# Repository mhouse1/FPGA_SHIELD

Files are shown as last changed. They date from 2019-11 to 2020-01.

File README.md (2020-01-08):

# FPGA_SHIELD
An awsome shield that supports multiple tranceivers

* Main schematic view
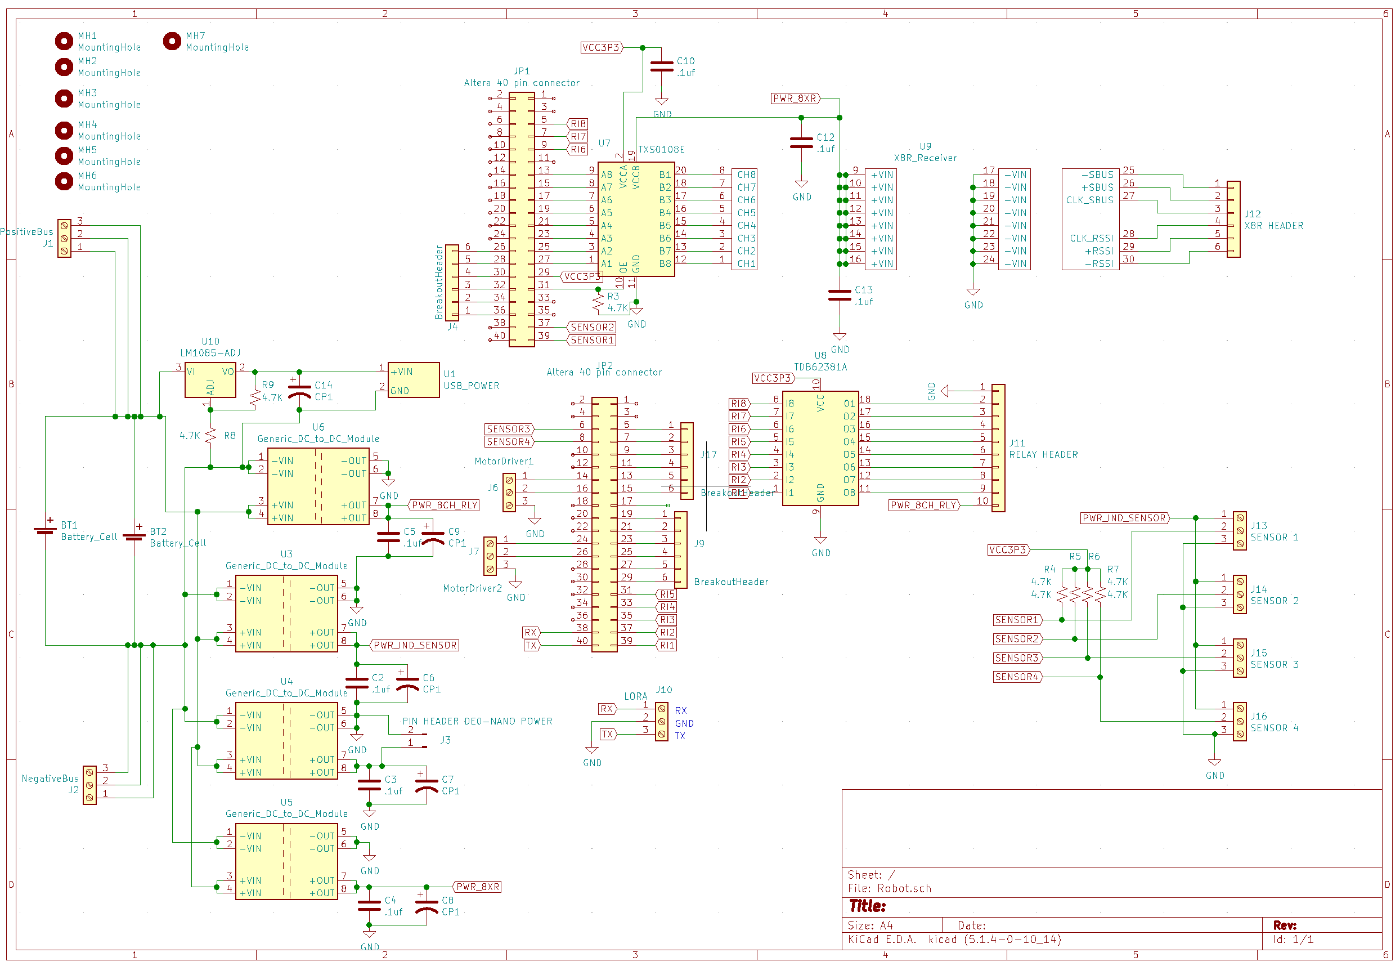
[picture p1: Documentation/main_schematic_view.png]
Main Schematic View


* board layout
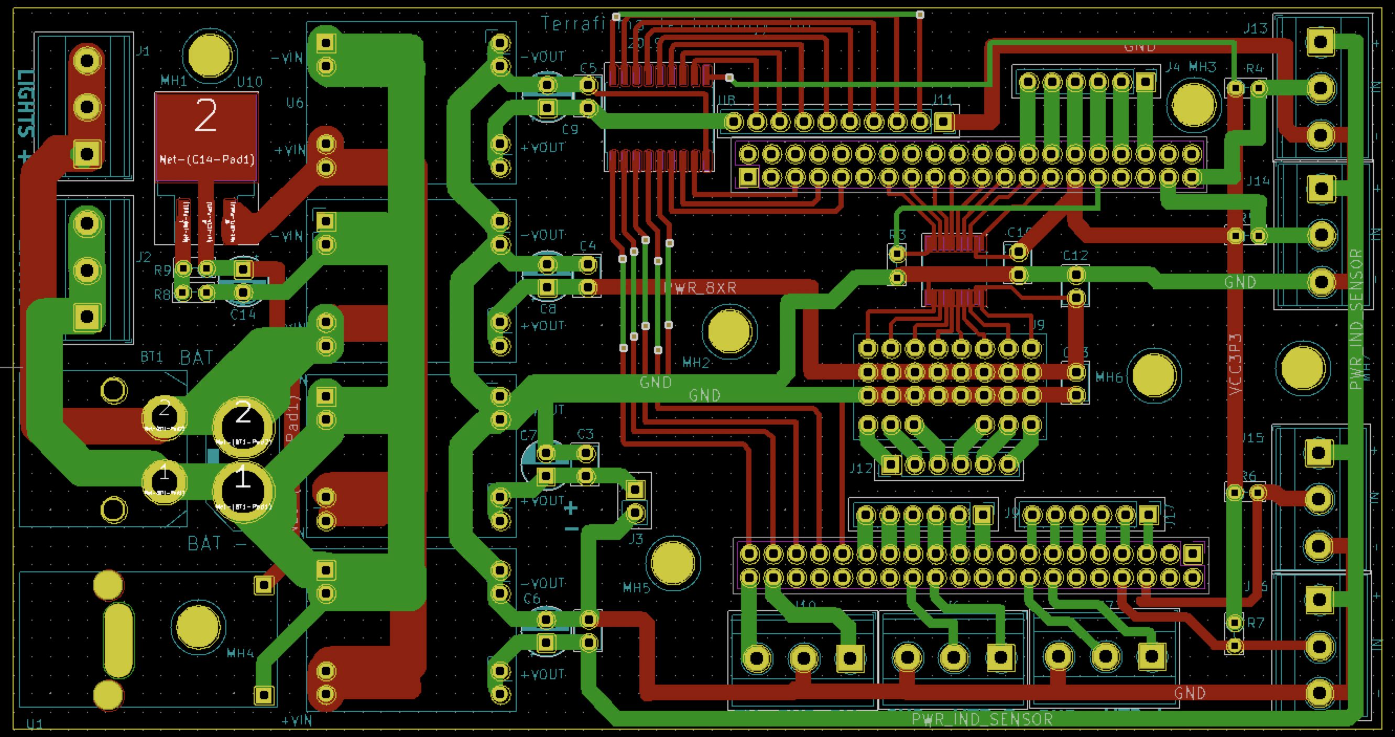
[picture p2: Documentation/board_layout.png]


* board model view 1
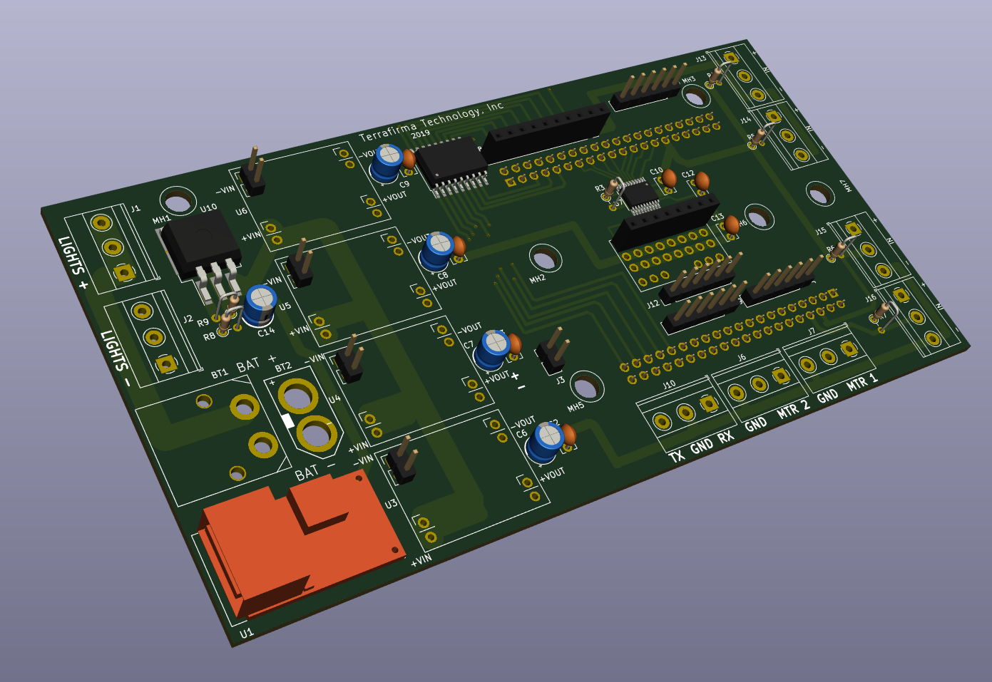
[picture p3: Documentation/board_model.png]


* board model view 2
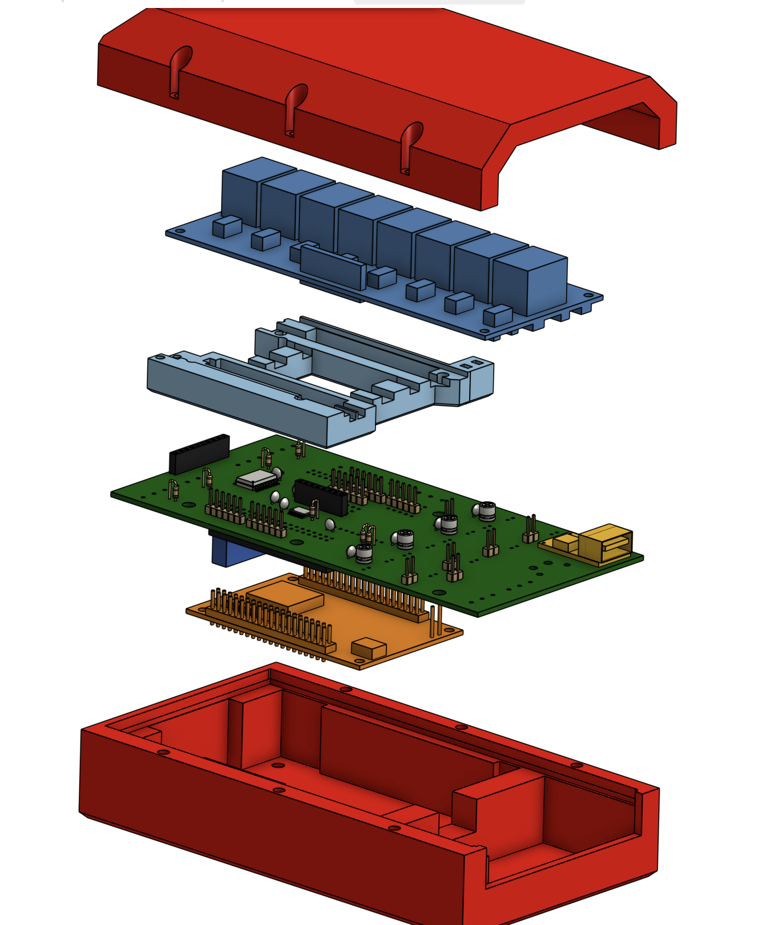
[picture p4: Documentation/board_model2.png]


* control board with relays
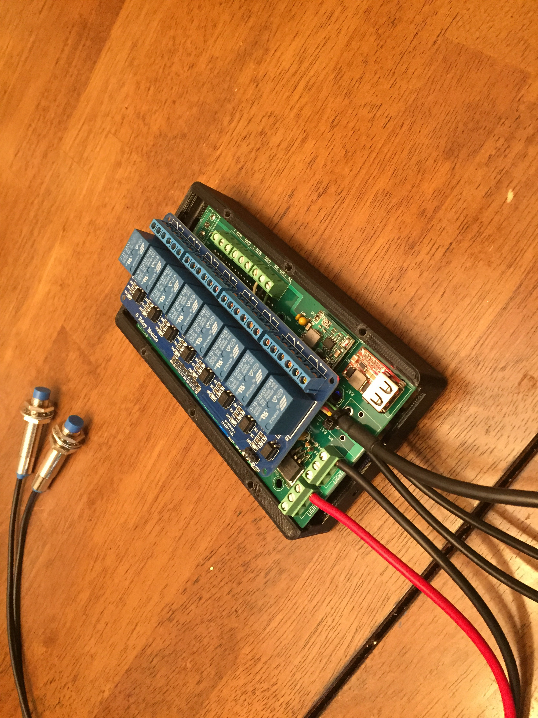
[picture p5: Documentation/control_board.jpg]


* assembled
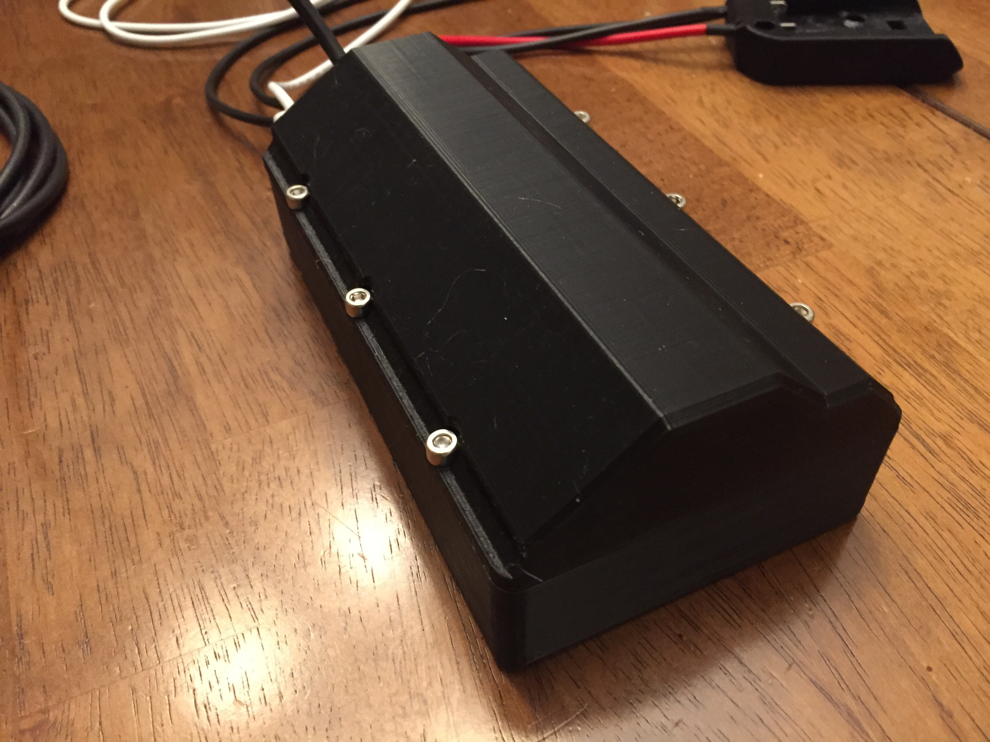
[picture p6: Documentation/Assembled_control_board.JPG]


* lora radios
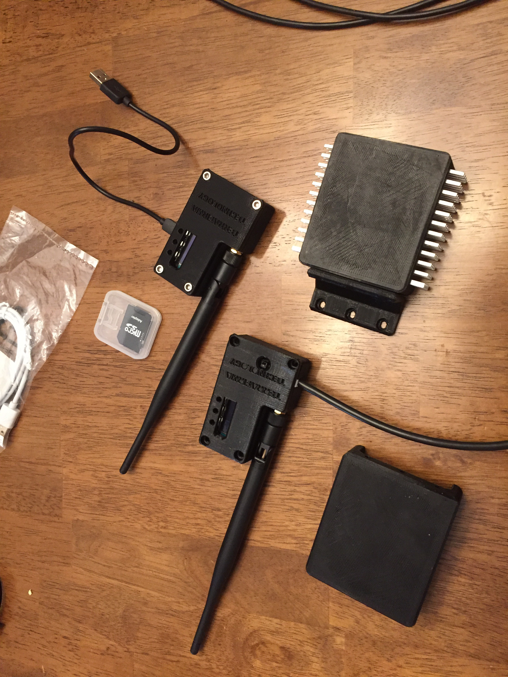
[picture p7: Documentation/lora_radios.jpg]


note: must adjust converters before powering on level shifting circuit, burned out the chip forgetting that on the first board.

changes for next version:
* xt60 wrong polarity
* ~~usb wrong polarity~~
* ~~usb flush mounting ( add holes for protruding USB pins)~~
* adjust J3 position (De nano power input)
* adjust JP2 position 
* add footprint for non PCB XT60
* adjust J6, J7, J10, J1, J2 position spacing to be same as J15, and J16 that way two or 3 position screw terminals can be used
* replace tantlum capacitors with ceramic capacitors?, replace with surface mount caps for easier assembly
* replace with surface mount resistors 
* move J11 and U8 to above JP1 so relay module is inline with PCB giving an overall smaller footprint for control board.
remove JP3
* delete/remove lora module
* add LM1085ISX-ADJ/NOPB or something similar for regulating power going to the USB converter
* add mini fuse, use keystone 3568
* replace terminal blocks with ED100/2DS	,

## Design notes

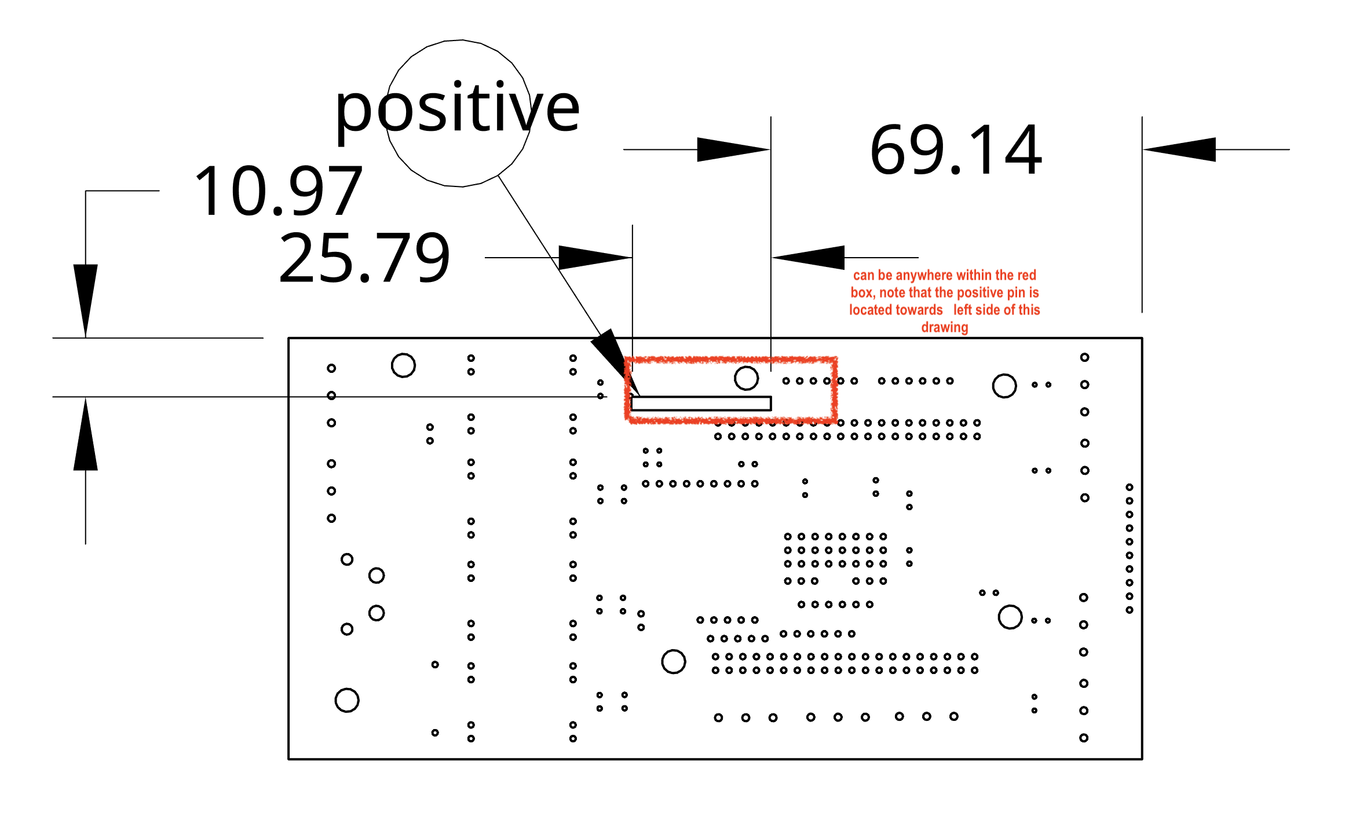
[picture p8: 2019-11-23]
Documentation/relay_board_relocation.png

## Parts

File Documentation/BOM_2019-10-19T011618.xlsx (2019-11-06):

Index | Quantity | Part Number | Manufacturer Part Number | Description | Customer Reference | Available | Backorder | Unit Price | Extended Price USD
1 | 2 | 296-23011-1-ND | TXS0108EPWR | IC TRNSLTR BIDIRECTIONAL 20TSSOP |  | 2 | 0 | 1.66 | 3.32
2 | 2 | TBD62381AFWGELCT-ND | TBD62381AFWG,EL | IC PWR DRIVER N-CHAN 1:1 18SOP |  | 2 | 0 | 1.39 | 2.78
3 | 4 | S6104-ND | PPTC202LFBN-RC | CONN HDR 40POS 0.1 TIN PCB |  | 4 | 0 | 2.29 | 9.16
4 | 2 | S7008-ND | PPTC101LFBN-RC | CONN HDR 10POS 0.1 TIN PCB |  | 2 | 0 | 0.65 | 1.30
5 | 5 | S7041-ND | PPPC081LFBN-RC | CONN HDR 8POS 0.1 GOLD PCB |  | 5 | 0 | 0.67 | 3.35
6 | 15 | S7035-ND | PPPC021LFBN-RC | CONN HDR 2POS 0.1 GOLD PCB |  | 15 | 0 | 0.315 | 4.73
7 | 4 | 732-5319-ND | 61300611121 | CONN HEADER VERT 6POS 2.54MM |  | 4 | 0 | 0.33 | 1.32
8 | 10 | 277-1248-ND | 1729131 | TERM BLK 3P SIDE ENT 5.08MM PCB |  | 10 | 0 | 1.582 | 15.82
9 | 2 | 4605X-101-103LF-ND | 4605X-101-103LF | RES ARRAY 4 RES 10K OHM 5SIP |  | 2 | 0 | 0.5 | 1.00
10 | 10 | CF18JT4K70CT-ND | CF18JT4K70 | RES 4.7K OHM 1/8W 5% CF AXIAL |  | 10 | 0 | 0.049 | 0.49
11 | 10 | 399-14036-1-ND | C320C104K5R5TA7317 | CAP CER 0.1UF 50V X7R RADIAL |  | 10 | 0 | 0.173 | 1.73
12 | 2 | 732-5315-ND | 61300211121 | CONN HEADER VERT 2POS 2.54MM |  | 2 | 0 | 0.13 | 0.26
13 | 5 | 478-1839-ND | TAP106K016SCS | CAP TANT 10UF 10% 16V RADIAL |  | 5 | 0 | 0.81 | 4.05

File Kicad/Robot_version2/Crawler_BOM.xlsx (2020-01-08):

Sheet: digikey
Index | Quantity | Part Number | Manufacturer Part Number | Description | Customer Reference | Backorder | Unit Price | Extended Price
1 | 100 | 732-5315-ND | 61300211121 | CONN HEADER VERT 2POS 2.54MM |  | 0 | 0.067 | $6.70
2 | 100 | 399-14036-1-ND | C320C104K5R5TA7317 | CAP CER 0.1UF 50V X7R RADIAL |  | 0 | 0.0978 | $9.78
3 | 50 | 277-1248-ND | 1729131 | TERM BLK 3P SIDE ENT 5.08MM PCB |  | 0 | 1.513 | $75.65
4 | 4 | 732-5319-ND | 61300611121 | CONN HEADER VERT 6POS 2.54MM |  | 0 | 0.33 | $1.32
5 | 50 | CF18JT4K70CT-ND | CF18JT4K70 | RES 4.7K OHM 1/8W 5% CF AXIAL |  | 0 | 0.0272 | $1.36
6 | 5 | S7041-ND | PPPC081LFBN-RC | CONN HDR 8POS 0.1 GOLD PCB |  | 0 | 0.67 | $3.35
7 | 10 | S7008-ND | PPTC101LFBN-RC | CONN HDR 10POS 0.1 TIN PCB |  | 0 | 0.574 | $5.74
8 | 10 | S6104-ND | PPTC202LFBN-RC | CONN HDR 40POS 0.1 TIN PCB |  | 0 | 2.075 | $20.75
9 | 2 | 296-23011-1-ND | TXS0108EPWR | IC TRNSLTR BIDIRECTIONAL 20TSSOP |  | 0 | 1.66 | $3.32
10 | 10 | TBD62381AFWGELCT-ND | TBD62381AFWG,EL | IC PWR DRIVER N-CHAN 1:1 18SOP |  | 0 | 1.182 | $11.82
11 | 25 | 478-9328-ND | TAP106M016SCS | CAP TANT 10UF 20% 16V RADIAL |  | 0 | 0.618 | $15.45
12 | 1 | S7037-ND | PPPC041LFBN-RC | CONN HDR 4POS 0.1 GOLD PCB |  | 0 | 0.47 | $0.47
13 | 20 | S7004-ND | PPTC061LFBN-RC | CONN HDR 6POS 0.1 TIN PCB |  | 0 | 0.483 | $9.66
14 | 10 | LM1085ISX-ADJ/NOPBCT-ND | LM1085ISX-ADJ/NOPB | IC REG LIN POS ADJ 3A DDPAK |  | 0 | 1.826 | $18.26
15 | 2 | 1528-2836-ND | 4074 | RFM95W 915MHZ LORA RADIO BONNET |  | 0 | 32.5 | $65.00
 |  | Note: be extra careful while soldering the 40pin connectors, do not solder while the FPGA is connected to the shield, the header may weld itself to the FPGA.
 |  | Note: be careful when removing the FPGA control board (DE0-nano),may damage the board if too much stress introduced while removing

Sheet: other_suppliers - Third party s
Third party suppliers
Supplier | Item Name | QTY | Link | Total $
Adafruit | 900Mhz Antenna Kit - For LoPy, LoRa, etc[ID:3340] | 2 | https://www.adafruit.com/product/3340 | 31.91
Amazon | eBoot 12 Pack Mini MP1584EN DC-DC Buck Converter Adjustable Power Step Down Module 24V to 12V 9V 5V 3V (12 Pack) | 1 | https://www.amazon.com/gp/product/B07RVG34WR/ref=ppx_yo_dt_b_asin_title_o02_s00?ie=UTF8&psc=1 | 12.25
Amazon | Amass XT60 XT60PW Plug Connector Male & Female 5 Pair for RC Battery Rc Models | 1 | https://www.amazon.com/gp/product/B071P6NHV5/ref=ppx_yo_dt_b_asin_title_o02_s00?ie=UTF8&psc=1 | 7.99
Amazon | TERASIC TECHNOLOGIES P0082 Cyclone IV, EP4CE22F17C6N, FPGA, DE0-NANO, DEV KIT | 1 | https://www.amazon.com/gp/product/B00MEKRXAE/ref=ox_sc_act_title_2?smid=A2L77EE7U53NWQ&psc=1 | 89
Amazon | SainSmart 8-Channel Relay Module | 1 | https://www.amazon.com/gp/product/B0057OC5WK/ref=ppx_yo_dt_b_asin_title_o09_s00?ie=UTF8&psc=1 | 10.99
Amazon (optional) | HRB Amass 5 Pairs XT60 Upgraded XT60U Plug 3.5mm Banana Connector Male and Female Motor Connector Bullet Plugs | 1 | https://www.amazon.com/gp/product/B07121P8BM/ref=ppx_yo_dt_b_asin_title_o02_s00?ie=UTF8&psc=1 | 7.19
Ebay | 6-24V 12V/24V to 5V 3A CAR USB Charger Module DC Buck step down Converter | 5 | https://www.ebay.com/itm/6-24V-12V-24V-to-5V-3A-CAR-USB-Charger-Module-DC-Buck-step-down-Converter/272320057515 | 8
Ebay | 5Pcs NC LJ12A3-4-Z/AX Inductive Proximity Sensor Switch NPN DC6V-36V US | 1 | https://www.ebay.com/itm/5Pcs-NC-LJ12A3-4-Z-AX-Inductive-Proximity-Sensor-Switch-NPN-DC6V-36V-US/301801245404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 | 14.99

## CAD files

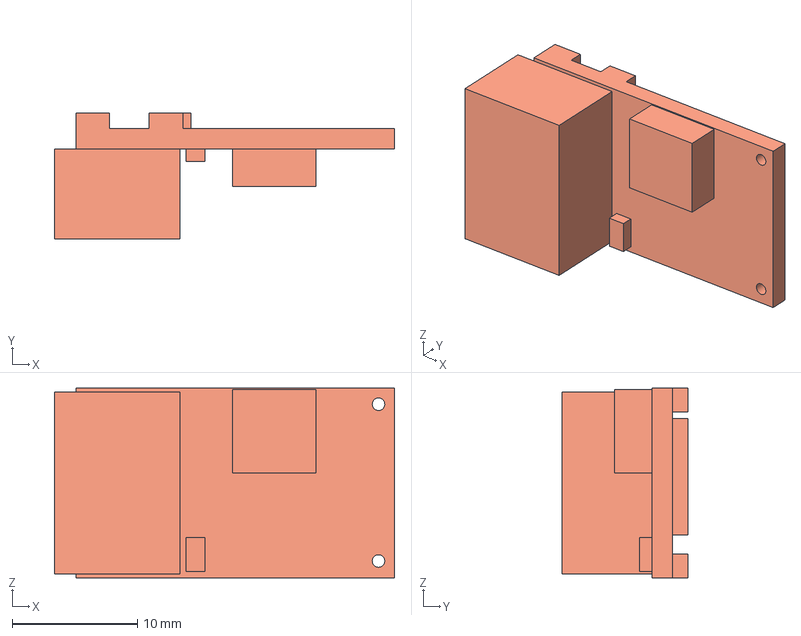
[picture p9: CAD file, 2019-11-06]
Kicad/Robot_version2/3D_CAD/20X2 - usb1.step
27.1 x 10.1 x 15.1 mm

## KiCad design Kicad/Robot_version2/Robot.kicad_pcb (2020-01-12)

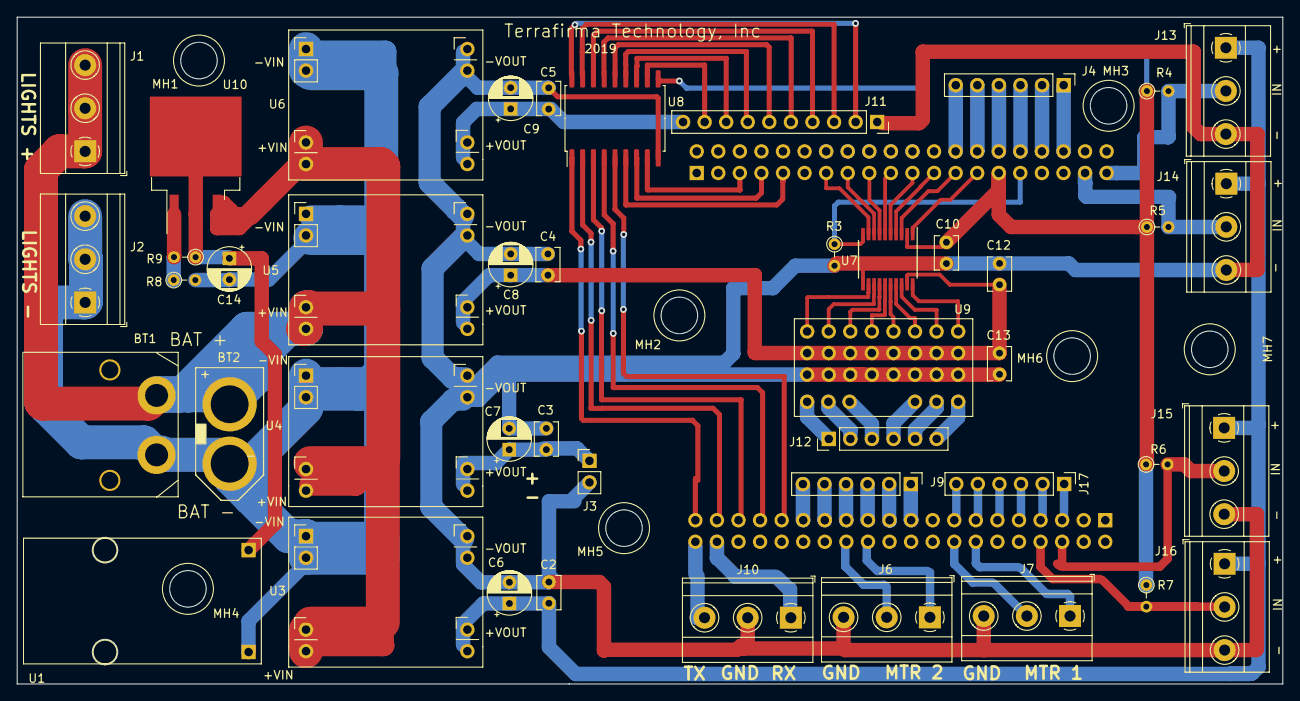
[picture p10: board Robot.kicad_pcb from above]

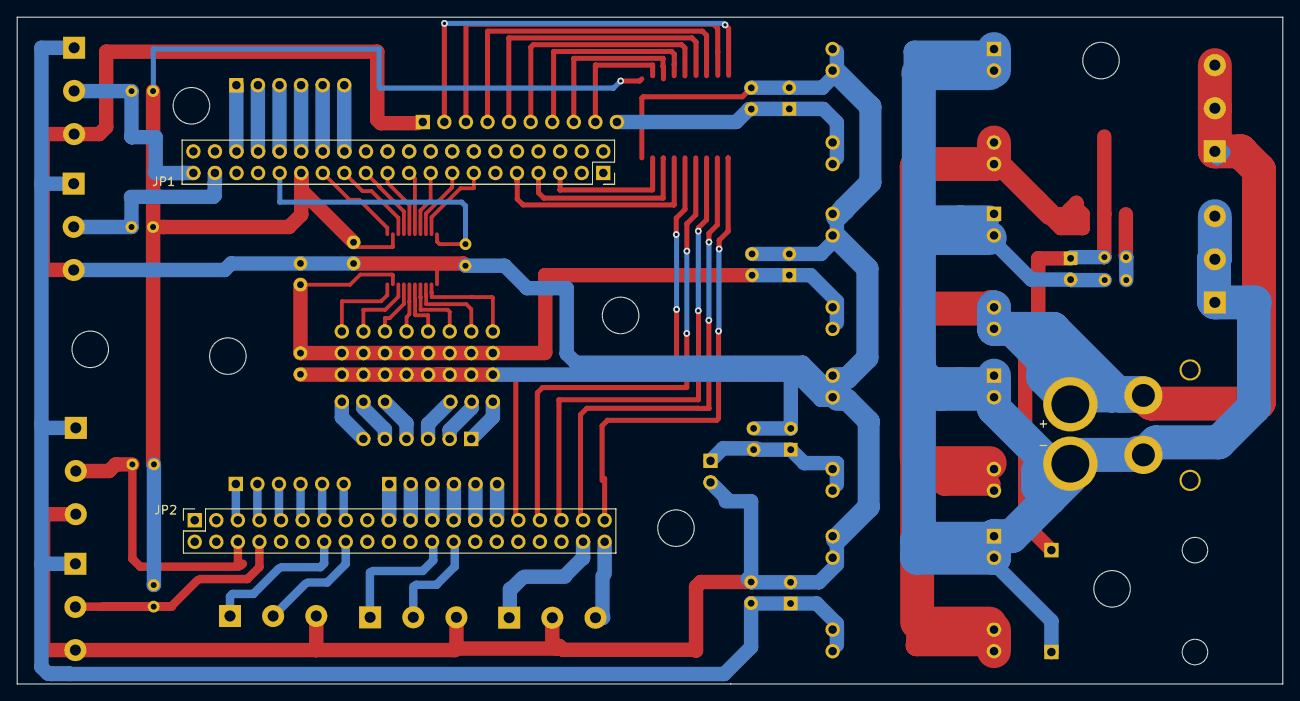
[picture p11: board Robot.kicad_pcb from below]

Board: 2 copper layers, 149.0 x 78.5 mm, 54 parts (2 on the bottom side), 77 nets.

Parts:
BT1: Battery_Cell; XT60PW
BT2: Battery_Cell; XT60_M
C2, C3, C4, C5, C10, C12, C13: .1uf; C_Disc_D3.8mm_W2.6mm_P2.50mm
C6, C7, C8, C9, C14: CP1; CP_Radial_D5.0mm_P2.50mm
J1: PositiveBus; TerminalBlock_Phoenix_MKDS-1,5-3-5.08_1x03_P5.08mm_Horizont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
J2: NegativeBus; TerminalBlock_Phoenix_MKDS-1,5-3-5.08_1x03_P5.08mm_Horizont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
J3: PIN HEADER DE0-NANO POWER; PinHeader_1x02_P2.54mm_Vertical
J4, J9, J17: BreakoutHeader; PinHeader_1x06_P2.54mm_Vertical
J6: MotorDriver1; TerminalBlock_Phoenix_MKDS-1,5-3-5.08_1x03_P5.08mm_Horizont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
J7: MotorDriver2; TerminalBlock_Phoenix_MKDS-1,5-3-5.08_1x03_P5.08mm_Horizont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
J10: LORA; TerminalBlock_Phoenix_MKDS-1,5-3-5.08_1x03_P5.08mm_Horizont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
J11: RELAY HEADER; PinSocket_1x10_P2.54mm_Vertical
J12: X8R HEADER; PinHeader_1x06_P2.54mm_Vertical
J13: SENSOR 1; TerminalBlock_Phoenix_MKDS-1,5-3-5.08_1x03_P5.08mm_Horizont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
J14: SENSOR 2; TerminalBlock_Phoenix_MKDS-1,5-3-5.08_1x03_P5.08mm_Horizont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
J15: SENSOR 3; TerminalBlock_Phoenix_MKDS-1,5-3-5.08_1x03_P5.08mm_Horizont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
J16: SENSOR 4; TerminalBlock_Phoenix_MKDS-1,5-3-5.08_1x03_P5.08mm_Horizont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
JP1, JP2: Altera 40 pin connector; PinSocket_2x20_P2.54mm_Vertical
MH1, MH2, MH3, MH4, MH5, MH6, MH7: MountingHole; MountingHole_4.3mm_M4
R3, R4, R5, R6, R7, R8, R9: 4.7K; R_Axial_DIN0204_L3.6mm_D1.6mm_P2.54mm_Vertical
U1: USB_POWER; USB_POWER_flush
U3, U4, U5, U6: Generic_DC_to_DC_Module; GEN_DC_TO_DC
U7: TXS0108E; TSSOP-20_4.4x6.5mm_P0.65mm
U8: TDB62381A; SOIC-18W_7.5x11.6mm_P1.27mm
U9: X8R_Receiver; X8R
U10: LM1085-ADJ; TO-263-3_TabPin2

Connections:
GND: C2.2, C3.2, C4.2, C5.2, C6.2, C7.2, C8.2, C9.2, C10.2, C12.2, C13.2, J3.2, J6.3, J7.3, J10.2, J11.1, J13.3, J14.3, J15.3, J16.3, R3.2, U3.5, U3.6, U4.5, U4.6, U5.5, U5.6, U6.5, U6.6, U7.11, U8.9, U9.17, U9.18, U9.19, U9.20, U9.21, U9.22, U9.23, U9.24
unnamed: BT1.1, BT2.1, C14.2, J2.1, J2.2, J2.3, R8.2, U1.2, U3.1, U3.2, U4.1, U4.2, U5.1, U5.2, U6.1, U6.2
unnamed: BT1.2, BT2.2, J1.1, J1.2, J1.3, U3.3, U3.4, U4.3, U4.4, U5.3, U5.4, U6.3, U6.4, U10.3
unnamed: C3.1, C7.1, J3.1, U4.7, U4.8
unnamed: C14.1, R9.1, U1.1, U10.2
unnamed: J4.1, JP1.36
unnamed: J4.2, JP1.34
unnamed: J4.3, JP1.32
unnamed: J4.4, JP1.30
unnamed: J4.5, JP1.28
unnamed: J4.6, JP1.26
unnamed: J6.1, JP2.14
unnamed: J6.2, JP2.16
unnamed: J7.1, JP2.24
unnamed: J7.2, JP2.26
unnamed: J9.1, JP2.19
unnamed: J9.2, JP2.21
unnamed: J9.3, JP2.23
unnamed: J9.4, JP2.25
unnamed: J9.5, JP2.27
unnamed: J9.6, JP2.29
unnamed: J11.2, U8.18
unnamed: J11.3, U8.17
unnamed: J11.4, U8.16
unnamed: J11.5, U8.15
unnamed: J11.6, U8.14
unnamed: J11.7, U8.13
unnamed: J11.8, U8.12
unnamed: J11.9, U8.11
unnamed: J12.1, U9.25
unnamed: J12.2, U9.26
unnamed: J12.3, U9.27
unnamed: J12.4, U9.28
unnamed: J12.5, U9.29
unnamed: J12.6, U9.30
unnamed: J17.1, JP2.5
unnamed: J17.2, JP2.7
unnamed: J17.3, JP2.9
unnamed: J17.4, JP2.11
unnamed: J17.5, JP2.13
unnamed: J17.6, JP2.15
unnamed: JP1.13, U7.9
unnamed: JP1.15, U7.8
unnamed: JP1.17, U7.7
unnamed: JP1.19, U7.6
unnamed: JP1.21, U7.5
unnamed: JP1.23, U7.4
unnamed: JP1.25, U7.3
unnamed: JP1.27, U7.1
unnamed: JP1.31, R3.1, U7.10
unnamed: R8.1, R9.2, U10.1
unnamed: U7.12, U9.1
unnamed: U7.13, U9.2
unnamed: U7.14, U9.3
unnamed: U7.15, U9.4
unnamed: U7.16, U9.5
unnamed: U7.17, U9.6
unnamed: U7.18, U9.7
unnamed: U7.20, U9.8
PWR_8CH_RLY: C5.1, C9.1, J11.10, U6.7, U6.8
PWR_8XR: C4.1, C8.1, C12.1, C13.1, U5.7, U5.8, U7.19, U9.9, U9.10, U9.11, U9.12, U9.13, U9.14, U9.15, U9.16
PWR_IND_SENSOR: C2.1, C6.1, J13.1, J14.1, J15.1, J16.1, U3.7, U3.8
RI1: JP2.39, U8.1
RI2: JP2.37, U8.2
RI3: JP2.35, U8.3
RI4: JP2.33, U8.4
RI5: JP2.31, U8.5
RI6: JP1.9, U8.6
RI7: JP1.7, U8.7
RI8: JP1.5, U8.8
RX: J10.1, JP2.38
SENSOR1: J13.2, JP1.39, R4.2
SENSOR2: J14.2, JP1.37, R5.2
SENSOR3: J15.2, JP2.6, R6.2
SENSOR4: J16.2, JP2.8, R7.2
TX: J10.3, JP2.40
VCC3P3: C10.1, JP1.29, R4.1, R5.1, R6.1, R7.1, U7.2, U8.10

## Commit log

2019-10-03 initial schematic
    [Robot.kicad_pcb, Robot.sch]
2019-10-03 updated naming
    [Robot.sch]
2019-10-03 updated schematic picture
2019-10-04 ADDED 3 PIN TERMINALS AND A NEW DRIVER RELAY
    ADDED 3 PIN TERMINALS AND NEW DRIVER FOR THE RELAY
    [Robot.sch]
2019-10-04 added screw terminals for lights and motor driver signals
    [Robot.sch]
2019-10-04 added LoRa module, connected 3.3v pullup to JP1, removed duplicate inductive sensor terminals
    [Robot.sch]
2019-10-07 All the decals are done. Need to discuss tommow power for LORA and x8R chip before starting to place and route the PCB
    All the decals are done.
    Need to discuss tommow power for LORA and x8R chip before starting to place and route the PCB
    [Robot.kicad_pcb, Robot.sch]
2019-10-08 UPDATE PS JUMPER AND LEVEL SHIFTER
    [Robot.sch]
2019-10-08 UPDATED PARTS ON PCB
    [Robot.kicad_pcb, Robot.sch]
2019-10-08 add decoupling caps
    added decoupling caps
    [Robot.kicad_pcb, Robot.sch]
2019-10-08 add sip resistor
    [Robot.kicad_pcb, Robot.sch]
2019-10-09 updates 2x20 header decal
    [Robot.kicad_pcb]
2019-10-10 fixed relay driver OE pin map, added breakout for unused pins, J15 and J16 are now + and - bus terminals
    [Robot.sch]
2019-10-11 fixed 2 pullups and added cap on output of dc to dc
    [Robot.kicad_pcb, Robot.sch]
2019-10-11 placed header
    [Robot.kicad_pcb, Robot.sch]
2019-10-13 Parts placement plus other changes
    parts placement plus other changes
    [Robot.kicad_pcb, Robot.sch]
2019-10-13 changes
    changes
    [Robot.kicad_pcb, Robot.sch]
2019-10-13 layout complete for review
    layout complete for review
    [Robot.kicad_pcb, Robot.sch]
2019-10-13 added mounting holes
    add mounting holes
    [Robot.kicad_pcb]
2019-10-14 fixed fpga power input and jp2 header, usb pad positions, added some more mounting holes
    [Robot.kicad_pcb]
2019-10-15 updated position of a few components on the board, generated output gerber files for first production
    [Robot-B_Cu.gbr, Robot-B_Mask.gbr, Robot-B_Paste.gbr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]
2019-10-16 first release board documentation
2019-11-06 fixed usb polarity, added usb 3d model, edited usb footprin for flush mounting, updated pictures
    [20X2 - usb1.step, BOM_2019-10-19T011618.xlsx, Robot.kicad_pcb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]
2019-11-06 updated usb foot print to remove copper from through holes
    [Robot.kicad_pcb]
2019-11-19 updated changes requested for V2 board
2019-11-19 updated picture of board
2019-11-23 added picture of relocated relay board diagram
2019-11-23 added drawing of general area for relay header
2019-11-23 rev 2 placement
    [Robot-B_Cu.gbr, Robot-B_Mask.gbr, Robot-B_Paste.gbr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]
2019-11-23 First draft of rev2
    [Robot.kicad_pcb, Robot.sch]
2019-11-24 fixed usb
    [Robot.kicad_pcb]
2019-11-24 moved parts closer
    [Robot.kicad_pcb]
2019-11-26 moved ref
    [Robot.kicad_pcb]
2019-12-14 updated schematic and layout for shield v2
    [Robot-B_Cu.gbl, Robot-B_Mask.gbs, Robot-B_SilkS.gbo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]
2019-12-14 updated picture of board, layout, and schematic
2020-01-08 added BOM, and minor updates
    [Crawler_BOM.xlsx, Robot.kicad_pcb, Robot.sch]
2020-01-12 moved jp2 and j3 -0.3X and -0.15Y
    [Robot.kicad_pcb]
